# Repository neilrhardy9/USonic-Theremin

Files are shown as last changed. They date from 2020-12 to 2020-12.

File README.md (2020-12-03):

# USonic-Theremin
A portable, rechargeable theremin using ultrasonic transducers for distance sensing. Connect the device to any consumer-grade speaker or directly to your computer to record your sound!

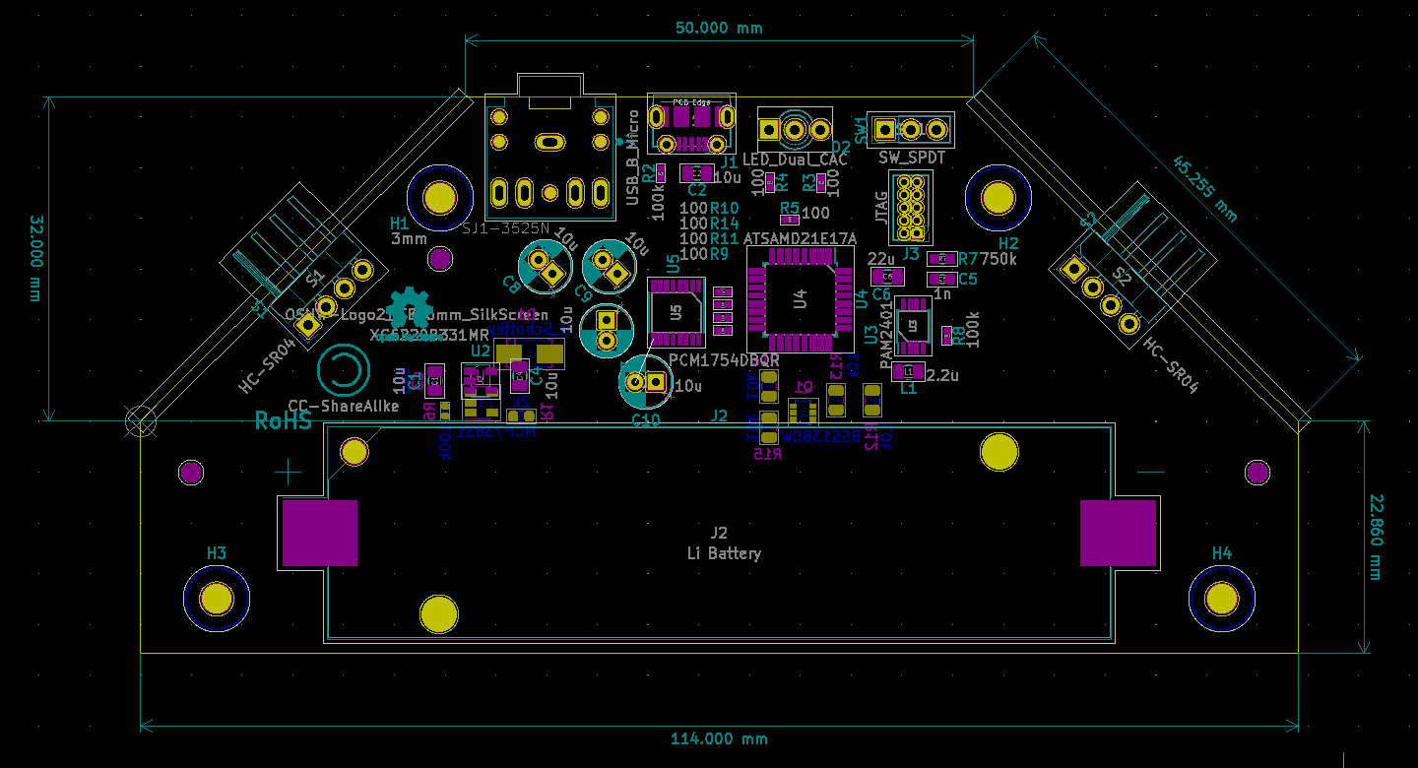
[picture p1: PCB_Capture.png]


Take a look at the <a href="Schematic_Capture.pdf">schematic<a/>
  
Feedback and derivatives are welcome! **NOTE** that the firmware files are licensed under a permissive MIT OSL, but the **hardware is licensed under a strongly reciprocal CERN-OHL-S license** which means all derivatives must undertake the same license.

Thanks,
Neil

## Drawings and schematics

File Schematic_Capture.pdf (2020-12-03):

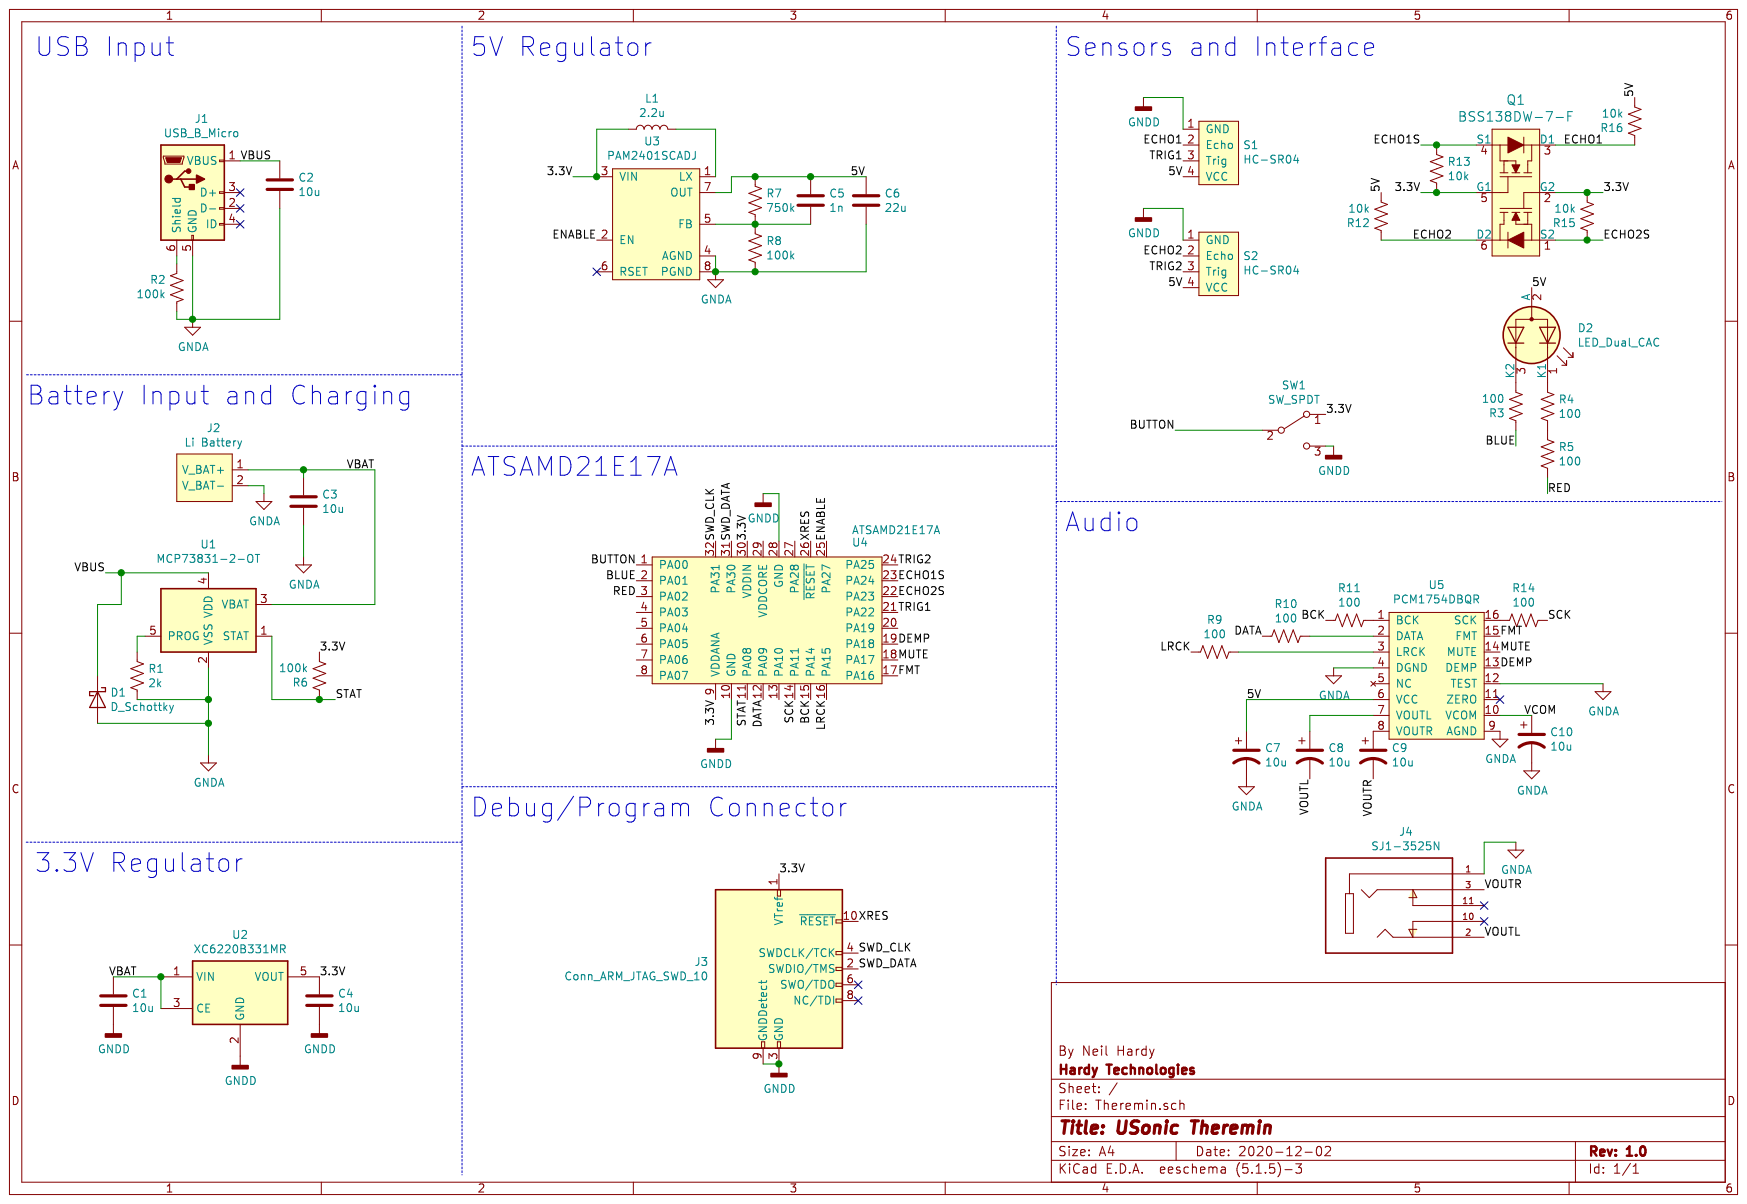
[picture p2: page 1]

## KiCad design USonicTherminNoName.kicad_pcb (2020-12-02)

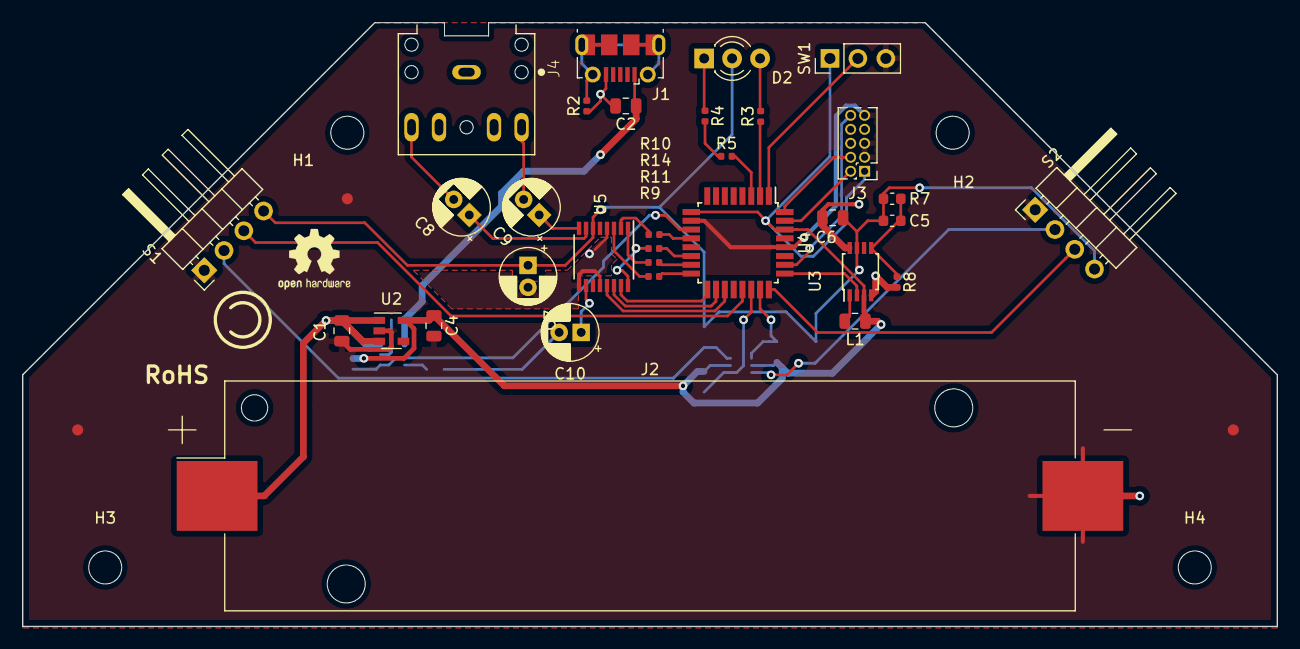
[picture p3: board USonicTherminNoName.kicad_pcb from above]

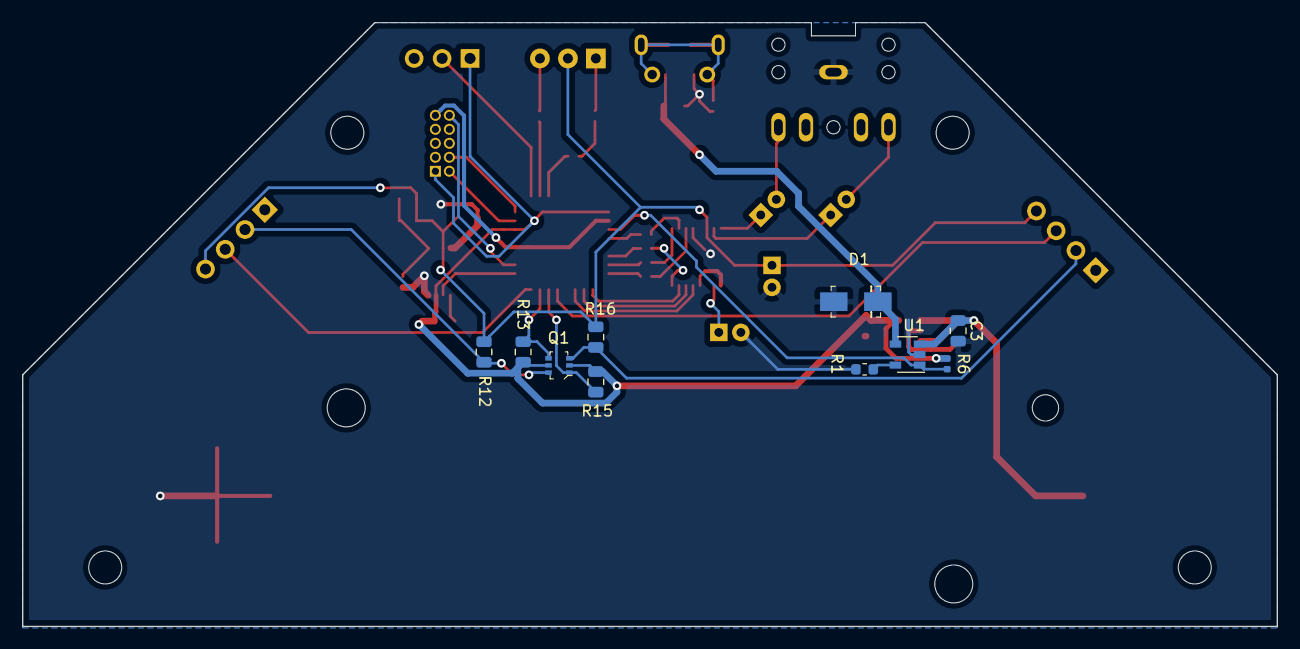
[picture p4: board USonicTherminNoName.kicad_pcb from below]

Board: 2 copper layers, 114.0 x 54.9 mm, 50 parts (10 on the bottom side), 43 nets.

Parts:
 : Fiducial_1mm_Mask2mm
 #2,  #3: Fiducial_1mm_Mask2mm
 #4: CC-ShareAlike; Symbol_CC-ShareAlike_CopperTop_Small
C1, C2, C3, C4: 10u; C_0805_2012Metric
C5: 1n; C_0603_1608Metric
C6: 22u; C_0805_2012Metric
C7, C8, C9, C10: 10u; CP_Radial_D5.0mm_P2.00mm
D1: D_Schottky; DO-214AC
D2: LED_Dual_CAC; LED_D3.0mm-3
H1: 3mm; MountingHole_3mm
H2, H3, H4: MountingHole_3mm
J1: USB_B_Micro; USB_Micro-B_Molex-105017-0001
J2: Li Battery; BatteryHolder_Keystone_1042_1x18650
J3: JTAG; PinHeader_2x05_P1.27mm_Vertical
J4: SJ1-3525N; CUI_SJ1-3525N
L1: 2.2u; L_0805_2012Metric
Q1: BSS138DW; SOT-363
R1: 2k; R_0603_1608Metric
R2, R6, R8: 100k; R_0402_1005Metric
R3, R4, R5, R9, R10, R11, R14: 100; R_0402_1005Metric
R7: 750k; R_0603_1608Metric
R12, R13, R15, R16: 10k; R_0805_2012Metric
S1, S2: HC-SR04; PinHeader_1x04_P2.54mm_Horizontal
SW1: SW_SPDT; PinHeader_1x03_P2.54mm_Vertical
U1: MCP73831; SOT-23-5
U2: XC6220B331MR; SOT-23-5
U3: PAM2401; TSSOP-8_3x3mm_P0.65mm
U4: ATSAMD21E17A; TQFP-32_7x7mm_P0.8mm
U5: PCM1754DBQR; SSOP-16_3.9x4.9mm_P0.635mm

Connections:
/3.3V: C4.1, J3.1, L1.1, Q1.2, Q1.5, R6.2, R13.2, R15.2, SW1.1, U2.5, U3.3, U4.9, U4.30
/5V: C5.1, C6.1, C7.1, D2.2, R7.1, R12.2, R16.2, S1.4, S2.4, U3.7, U5.6
/BCK: R11.2, U4.15
/BLUE: R3.1, U4.2
/BUTTON: SW1.2, U4.1
/DATA: R10.2, U4.12
/DEMP: U4.19, U5.13
/ECHO1: Q1.3, R16.1, S1.2
/ECHO1S: Q1.4, R13.1, U4.23
/ECHO2: Q1.6, R12.1, S2.2
/ECHO2S: Q1.1, R15.1, U4.22
/ENABLE: U3.2, U4.25
/FMT: U4.17, U5.15
/LRCK: R9.2, U4.16
/MUTE: U4.18, U5.14
/RED: R5.2, U4.3
/SCK: R14.1, U4.14
/STAT: R6.1, U1.1, U4.11
/SWD_CLK: J3.4, U4.32
/SWD_DATA: J3.2, U4.31
/TRIG1: S1.3, U4.21
/TRIG2: S2.3, U4.24
/VBAT: C1.1, C3.1, J2.1, U1.3, U2.1, U2.3
/VBUS: C2.1, D1.1, J1.1, U1.4
/VCOM: C10.1, U5.10
/VOUTL: C8.2, J4.2
/VOUTR: C9.2, J4.3
/XRES: J3.10, U4.26
GNDA: C2.2, C3.2, C6.2, C7.2, C10.2, D1.2, J1.5, J2.2, J4.1, R1.2, R2.1, R8.2, U1.2, U3.4, U3.8, U5.4, U5.9, U5.12
GNDD: C1.2, C4.2, J3.3, J3.5, J3.9, S1.1, S2.1, SW1.3, U2.2, U4.10, U4.28
unnamed: C5.2, R7.2, R8.1, U3.5
unnamed: C8.1, U5.7
unnamed: C9.1, U5.8
unnamed: D2.1, R4.1
unnamed: D2.3, R3.2
unnamed: J1.6, R2.2
unnamed: L1.2, U3.1
unnamed: R1.1, U1.5
unnamed: R4.2, R5.1
unnamed: R9.1, U5.3
unnamed: R10.1, U5.2
unnamed: R11.1, U5.1
unnamed: R14.2, U5.16

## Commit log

2020-12-02 Uploaded KiCAD project, board, and gerber files
    I'm late to documenting the project, but better than never
    [USonicTherminNoName-B_Cu.gbr, USonicTherminNoName-B_Mask.gbr, USonicTherminNoName-B_SilkS.gbr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]
2020-12-02 put files in KiCAD directory
    [USonicTherminNoName-B_Cu.gbr, USonicTherminNoName-B_Mask.gbr, USonicTherminNoName-B_SilkS.gbr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]
